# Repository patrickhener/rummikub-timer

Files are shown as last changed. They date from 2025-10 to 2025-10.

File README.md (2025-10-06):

# Rummikub Timer

This project is a Rummikub timer. It has the following functions:

- Set a countdown time (default: 1 minute)
- Start timer by pressing big button
- Reset and start timer by pressing it again
- Blink big button when reaching 10 second time zone
- Alarm if time is up
- Nice laser-cut enclosure
- Runs on battery
- Chargable via USB-C
- Incorporates a display

## Hardware

The project consists of the following components:

- Arduino Nano
- LiPo Battery
- TP4056 USB-C charging 
- Different push buttons (28mm, 100mm with LED)
- On/Off Switch
- Active Buzzer
- MT3608 Step-Up Converter
- 0,96" OLED Display
- Small components like resistors and a mosfet

## Images

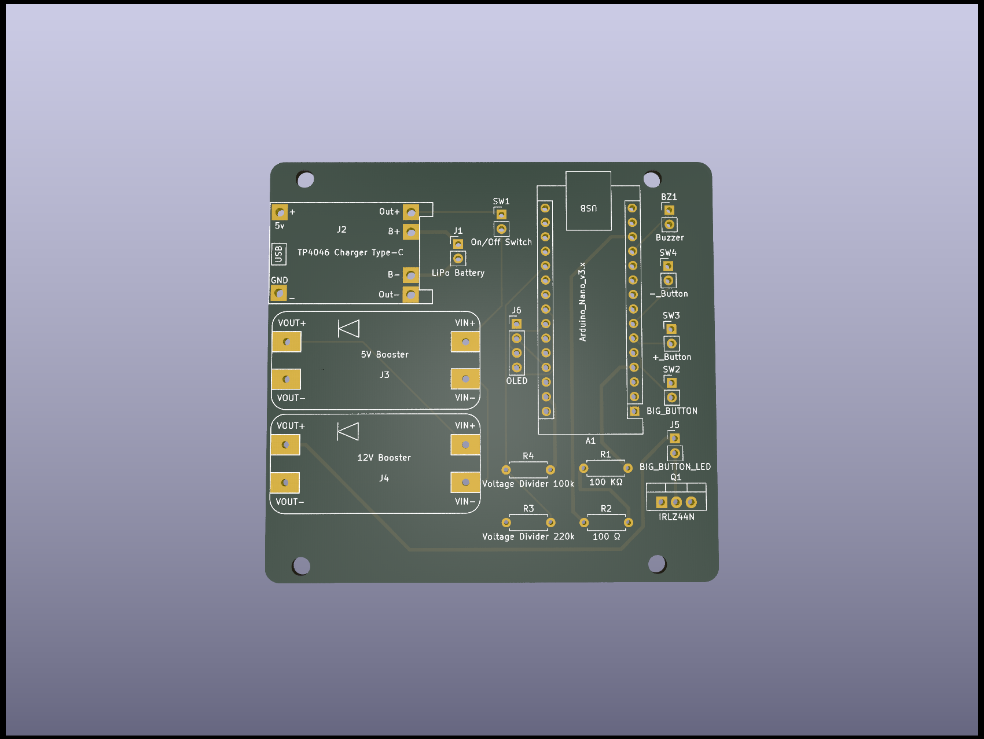
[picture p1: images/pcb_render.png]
PCB Render - Kicad


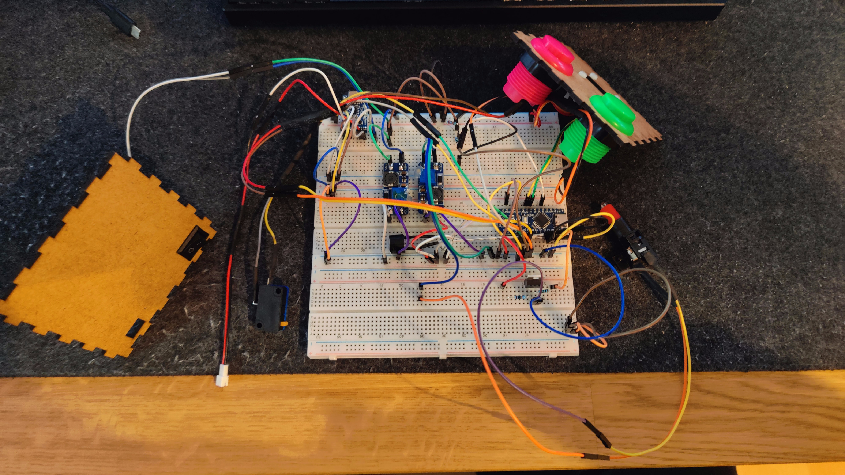
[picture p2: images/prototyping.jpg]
Prototyping


PCB top face

PCB bottom face

PCB test

Box really tight

Final box front

Final box back

## Lessons learned

The box is really tight, so I had to improvise and cut away from some of the buttons. Also The top button is not fixed into casing as it is to tight. But that in fact is better, so you can assamble and then maintaine it, by just pulling the big button out. As the button will be pushed it is not a problem it is not fixed anyways.

## Hazard warning

If you build it like I did never run and charge at the same time. The missing safe charge circuit during load is not sharing the load, so the battery will be over-charged and might caught on fire. I DO NOT HOLD ACCOUNTABILITY FOR DAMAGE TO YOU OR YOUR SURROUNDINGS.

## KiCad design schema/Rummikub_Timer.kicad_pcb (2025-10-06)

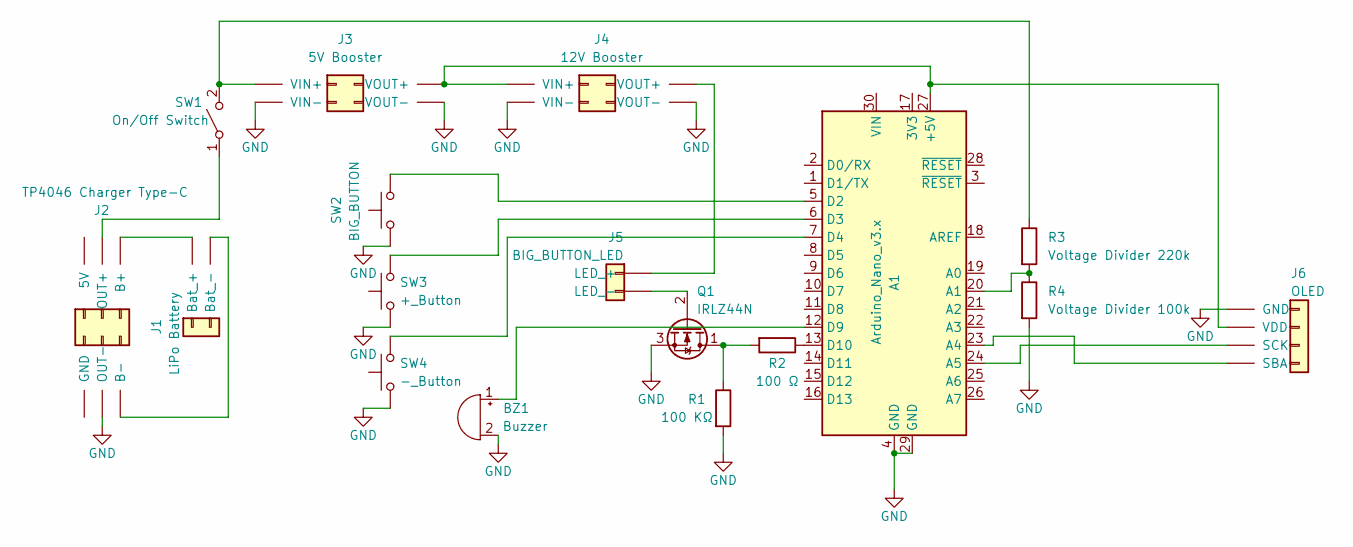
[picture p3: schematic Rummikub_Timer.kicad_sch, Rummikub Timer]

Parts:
A1: Arduino_Nano_v3.x; Arduino_Nano
BZ1: Buzzer; PinHeader_1x02_P2.54mm_Vertical
J1: LiPo Battery; PinHeader_1x02_P2.54mm_Vertical
J2: TP4046 Charger Type-C; TP4056-18650
J3: 5V Booster; MT3608_module
J4: 12V Booster; MT3608_module
J5: BIG_BUTTON_LED; PinHeader_1x02_P2.54mm_Vertical
J6: OLED; PinHeader_1x04_P2.54mm_Vertical
Q1: IRLZ44N; TO-220-3_Vertical
R1: 100 KΩ; R_Axial_DIN0207_L6.3mm_D2.5mm_P7.62mm_Horizontal
R2: 100 Ω; R_Axial_DIN0207_L6.3mm_D2.5mm_P7.62mm_Horizontal
R3: Voltage Divider 220k; R_Axial_DIN0207_L6.3mm_D2.5mm_P7.62mm_Horizontal
R4: Voltage Divider 100k; R_Axial_DIN0207_L6.3mm_D2.5mm_P7.62mm_Horizontal
SW1: On/Off Switch; PinHeader_1x02_P2.54mm_Vertical
SW2: BIG_BUTTON; PinHeader_1x02_P2.54mm_Vertical
SW3: +_Button; PinHeader_1x02_P2.54mm_Vertical
SW4: -_Button; PinHeader_1x02_P2.54mm_Vertical

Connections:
GND: A1.4 (GND), A1.29 (GND), BZ1.2 (+), J2.4 (OUT-), J3.2 (VIN-), J3.4 (VOUT-), J4.2 (VIN-), J4.4 (VOUT-), J6.1 (GND), Q1.3 (S), R1.2, R4.2, SW2.1, SW3.1, SW4.1
unnamed: A1.5 (D2), SW2.2
unnamed: A1.6 (D3), SW3.2
unnamed: A1.7 (D4), SW4.2
unnamed: A1.12 (D9), BZ1.1 (-)
unnamed: A1.13 (D10), R2.1
unnamed: A1.20 (A1), R3.2, R4.1
unnamed: A1.23 (A4), J6.4 (SBA)
unnamed: A1.24 (A5), J6.3 (SCK)
unnamed: A1.27 (+5V), J3.3 (VOUT+), J4.1 (VIN+), J6.2 (VDD)
unnamed: J1.1 (Bat_+), J2.5 (B+)
unnamed: J1.2 (Bat_-), J2.6 (B-)
unnamed: J2.3 (OUT+), SW1.1 (A)
unnamed: J3.1 (VIN+), R3.1, SW1.2 (B)
unnamed: J4.3 (VOUT+), J5.1 (LED_+)
unnamed: J5.2 (LED_-), Q1.2 (G)
unnamed: Q1.1 (D), R1.1, R2.2

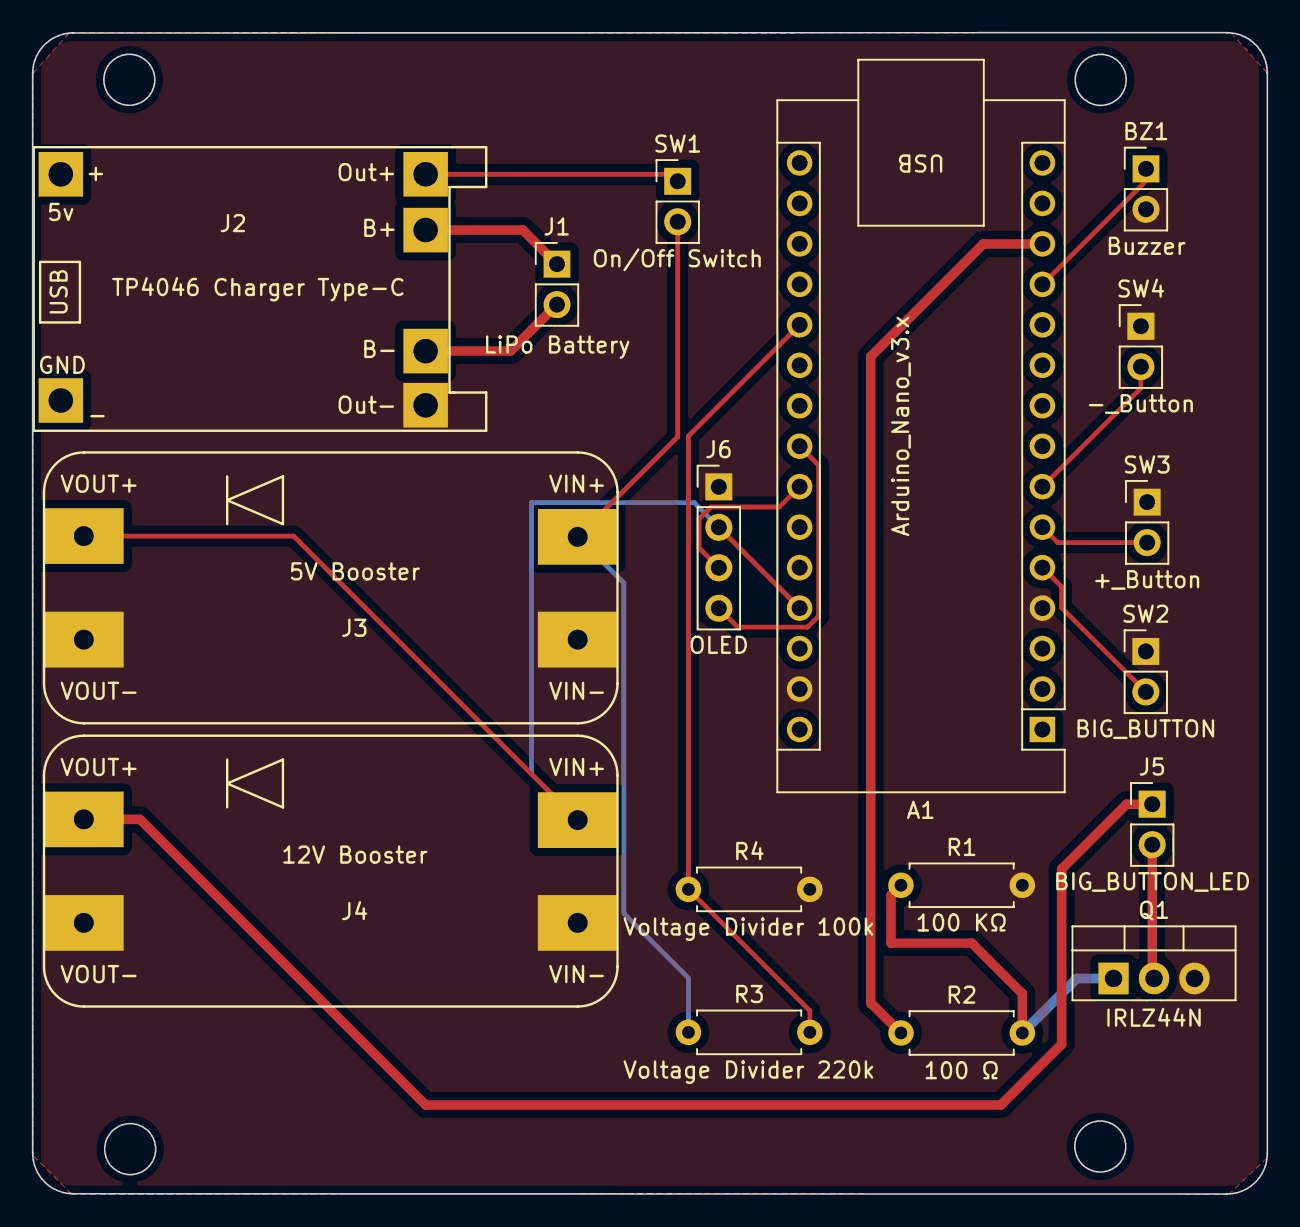
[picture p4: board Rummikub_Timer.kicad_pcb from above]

Board: 2 copper layers, 77.5 x 72.9 mm, 17 parts (0 on the bottom side), 17 nets.

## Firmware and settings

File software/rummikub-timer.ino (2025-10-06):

#include <Wire.h>
#include <Adafruit_GFX.h>
#include <Adafruit_SSD1306.h>

// ===== Display setup =====
#define SCREEN_WIDTH 128
#define SCREEN_HEIGHT 64
Adafruit_SSD1306 display(SCREEN_WIDTH, SCREEN_HEIGHT, &Wire, -1);

// ===== Pins =====
const int BTN_START = 2;
const int BTN_PLUS  = 3;
const int BTN_MINUS = 4;
const int BUZZER    = 9;
const int BATT_PIN  = A1;
const int LED_PIN = 10;   // transistor controlling arcade LED
bool ledState = false;
unsigned long lastBlink = 0;

// ===== State machine =====
enum State { IDLE, RUNNING, ALARM };
State state = IDLE;

// ===== Timer =====
unsigned long prevMillis = 0;
unsigned long lastSecond = 0;
int setSeconds = 60;      // default: 1:00
int remaining = 60;
const int STEP = 10;      // adjust in 10s steps

// ===== Helper: battery =====
float readBatteryVoltage() {
  int raw = analogRead(BATT_PIN);
  float vAdc = (raw / 1023.0) * 5.0;    // Nano = 5V ADC ref
  float vBat = vAdc * 3.2;              // Divider: (220k+100k)/100k = 3.2
  return vBat;
}

int batteryPercent() {
  float v = readBatteryVoltage();
  if (v > 4.2) v = 4.2;
  if (v < 3.3) v = 3.3;
  return (int)((v - 3.3) * 100.0 / (4.2 - 3.3)); // map 3.3–4.2V → 0–100%
}

// ===== Helper: draw battery icon =====
void drawBatteryIcon(int x, int y, int percent) {
  display.drawRect(x, y, 18, 8, SSD1306_WHITE);   // outline
  display.fillRect(x+18, y+2, 2, 4, SSD1306_WHITE); // nub
  int bars = map(percent, 0, 100, 0, 4);
  for (int i=0; i<bars; i++) {
    display.fillRect(x+2 + i*4, y+2, 3, 4, SSD1306_WHITE);
  }
}

// ===== Format MM:SS =====
void drawTimeLarge(int secs) {
  int m = secs / 60;
  int s = secs % 60;
  char buf[6];
  sprintf(buf, "%02d:%02d", m, s);
  display.setTextSize(4);
  display.setCursor(6, 24);
  display.print(buf);
}

void setup() {
  pinMode(BTN_START, INPUT_PULLUP);
  pinMode(BTN_PLUS, INPUT_PULLUP);
  pinMode(BTN_MINUS, INPUT_PULLUP);
  pinMode(BUZZER, OUTPUT);
  pinMode(LED_PIN, OUTPUT);
  digitalWrite(LED_PIN, HIGH); // LED on in idle

  if (!display.begin(SSD1306_SWITCHCAPVCC, 0x3C)) {
    for (;;); // hang if OLED not found
  }
  display.clearDisplay();
  display.display();
}

void loop() {
  unsigned long now = millis();

  // ===== Read buttons (active LOW) =====
  bool startPressed = !digitalRead(BTN_START);
  bool plusPressed  = !digitalRead(BTN_PLUS);
  bool minusPressed = !digitalRead(BTN_MINUS);

  // ===== State machine =====
  switch (state) {
    case IDLE:
      digitalWrite(LED_PIN, HIGH); // always on
      if (plusPressed) {
        setSeconds += STEP;
        delay(200); // crude debounce
      }
      if (minusPressed && setSeconds > STEP) {
        setSeconds -= STEP;
        delay(200);
      }
      if (startPressed) {
        remaining = setSeconds;
        lastSecond = now;
        state = RUNNING;
        delay(200);
      }
      break;

    case RUNNING:
      if (remaining <= 10) {
          if (now - lastBlink >= 500) {  // blink every 500 ms
            lastBlink = now;
            ledState = !ledState;
            digitalWrite(LED_PIN, ledState ? HIGH : LOW);
          }
      } else {
          digitalWrite(LED_PIN, HIGH); // solid on until last 10s
      }
      if (startPressed) { // restart
        remaining = setSeconds;
        lastSecond = now;
        delay(200);
      }
      if (now - lastSecond >= 1000) { // tick
        lastSecond += 1000;
        if (remaining > 0) {
          remaining--;
        } else {
          state = ALARM;
        }
      }
      break;

    case ALARM:
      digitalWrite(LED_PIN, LOW); // off
      digitalWrite(BUZZER, HIGH);
      delay(1000);
      digitalWrite(BUZZER, LOW);
      state = IDLE;
      break;
  }

  // ===== Display update =====
  display.clearDisplay();
  display.setTextColor(SSD1306_WHITE);

  int batt = batteryPercent();
  drawBatteryIcon(104, 0, batt);

  if (state == IDLE) {
    display.setTextSize(1);
    display.setCursor(0, 0);
    display.print("Set:");
    drawTimeLarge(setSeconds);
  }
  else if (state == RUNNING) {
    drawTimeLarge(remaining);
  }
  else if (state == ALARM) {
    display.setTextSize(2);
    display.setCursor(10, 24);
    display.print("TIME UP!");
  }

  display.display();
}
